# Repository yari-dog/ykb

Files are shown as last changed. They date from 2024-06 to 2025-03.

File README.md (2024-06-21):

## PCB
using 
 - https://github.com/ebastler/marbastlib for choc and controller (0xCB helios) footprints

for whatever reason, the GC9A01 board that i've designed this around uses i2c names instead of spi names, however it does indeed use spi. I've chosen to use the labels printed on the solder mask of the LCD as opposed to the correct SPI ones.

# thanks to pat for double checking my work lmao


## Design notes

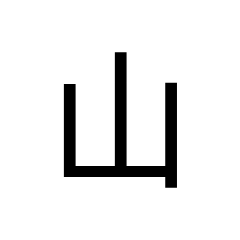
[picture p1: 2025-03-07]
qmk/yama.png

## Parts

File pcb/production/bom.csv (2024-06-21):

Designator | Footprint | Quantity | Value | LCSC Part #
_10, _9, _8, _7, _6, _5, _4, _3, _2, |  | 10
D1, D10, D11, D12, D13, D14, D15, D16, D17, D18, D19, D2, D20, D21, D22, D23, D24, D25, D26, D27, D28, D29, D3, D30, D31, D32, D33, D34, D35, D36, D37, D38, D39, D4, D40, D41, D42, D43, D44, D5, D6, D7, D8, D9 | Diode_SOD-123 | 44 | Diode
J1 | PinHeader_1x07_P2.54mm_Vertical | 1 | Conn_01x07_Socket
S1, S10, S11, S12, S13, S14, S15, S16, S17, S18, S19, S2, S20, S21, S22, S23, S24, S25, S26, S27, S28, S29, S3, S30, S31, S32, S33, S34, S35, S36, S37, S38, S39, S4, S40, S41, S42, S43, S44, S5, S6, S7, S8, S9 | Hotswap_Choc_V1V2_1.00u | 44 | Keyswitch

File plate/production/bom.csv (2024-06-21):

Designator | Footprint | Quantity | Value | LCSC Part #
_5, _4, _3, _2, |  | 5

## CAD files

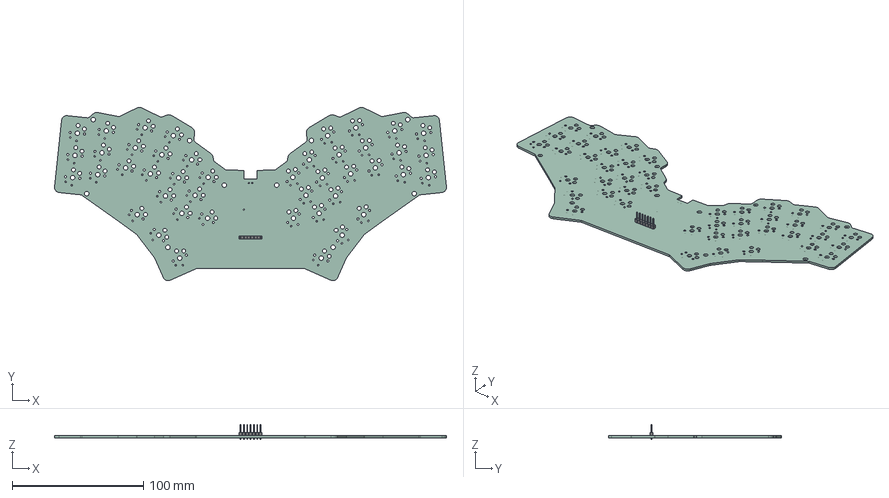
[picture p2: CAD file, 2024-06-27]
pcb/ykb.step
299.2 x 132.3 x 11.5 mm
PinHeader_1x07_P254mm_Vertical
_autosave-ykb_PCB
ykb_PCB

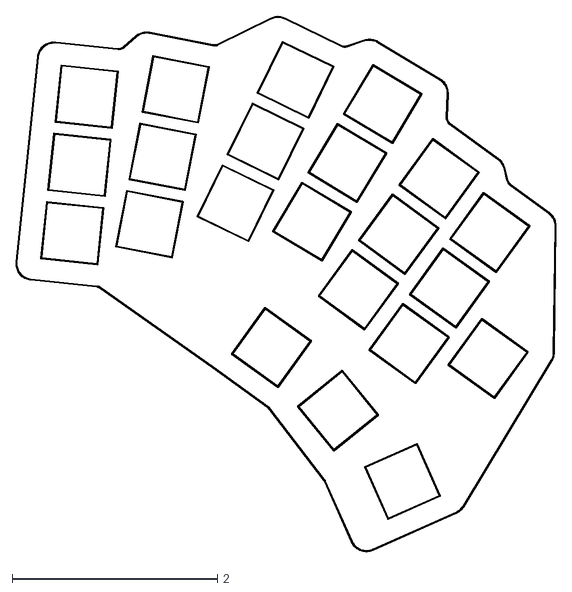
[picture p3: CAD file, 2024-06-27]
plate/yplate-Edge_Cuts.dxf
5.26 x 5.22

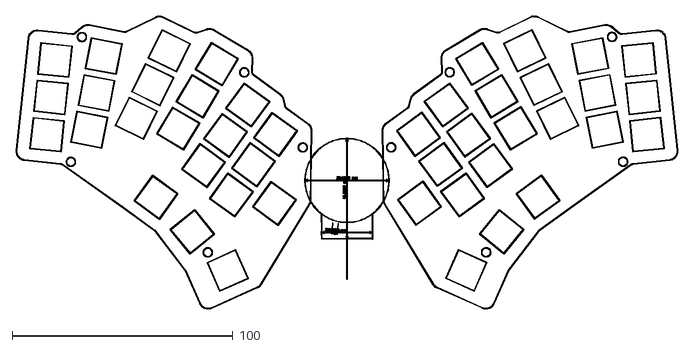
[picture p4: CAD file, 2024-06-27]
pcb/ykb-User_Drawings.dxf
299.4 x 132.5

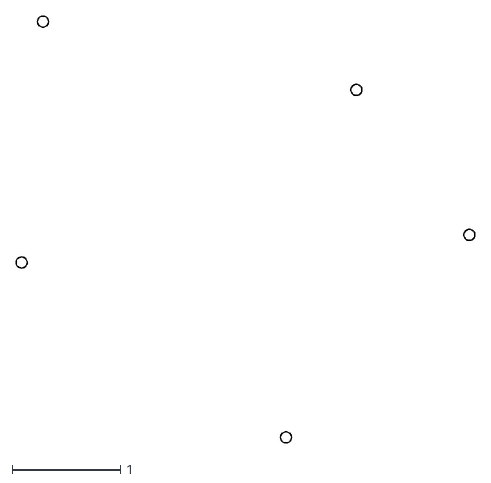
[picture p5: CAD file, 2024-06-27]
plate/yplate-F_Cu.dxf
4.24 x 3.94

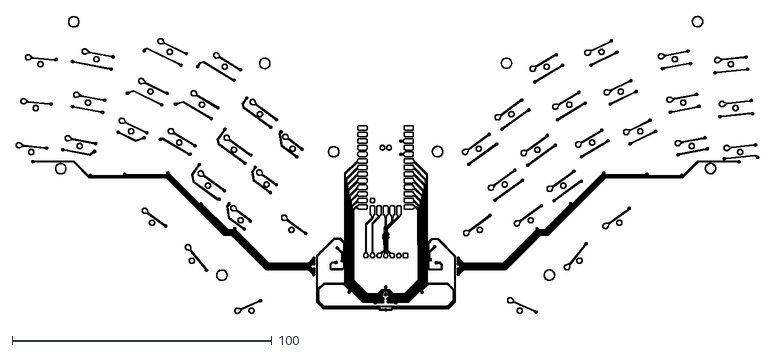
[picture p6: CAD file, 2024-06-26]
pcb/ykb-F_Cu.dxf
285.7 x 114.3

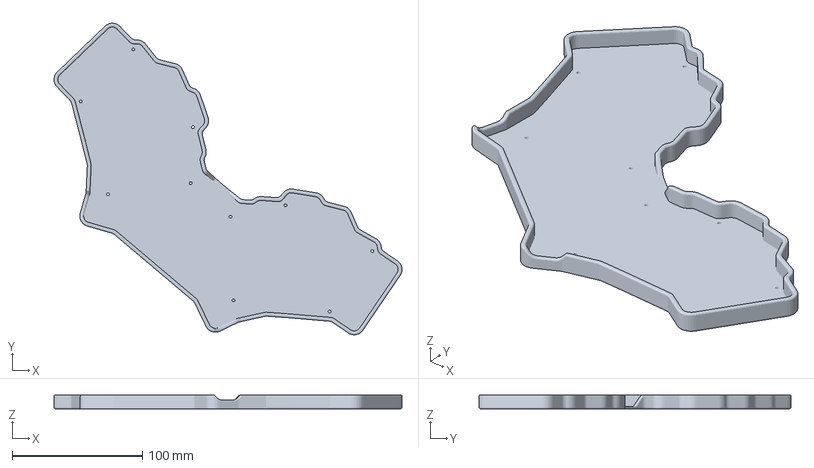
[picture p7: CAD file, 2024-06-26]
pcb/ykb case v47.3mf
267.0 x 239.2 x 11.0 mm

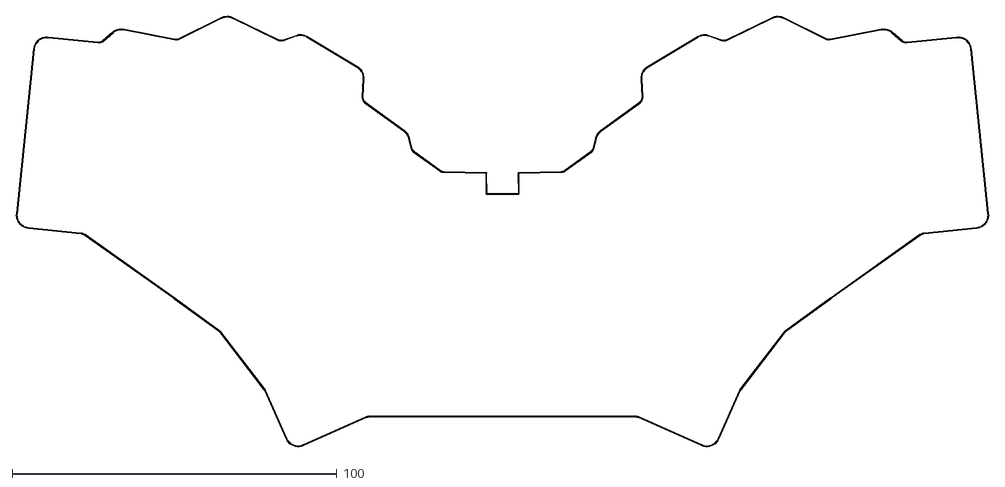
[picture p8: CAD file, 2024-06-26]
pcb/ykb-Edge_Cuts.dxf
299.3 x 132.4

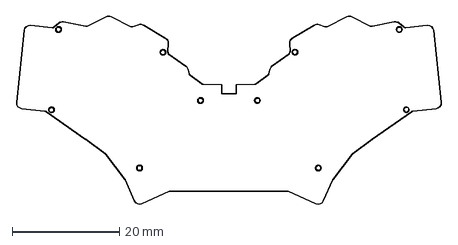
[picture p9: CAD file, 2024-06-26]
pcb/pcb outline with 4mm holes!.dxf
79.2 x 35.2 mm

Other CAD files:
pcb/ImageToStl.com_ykb.obj
pcb/ykb case v47.f3d

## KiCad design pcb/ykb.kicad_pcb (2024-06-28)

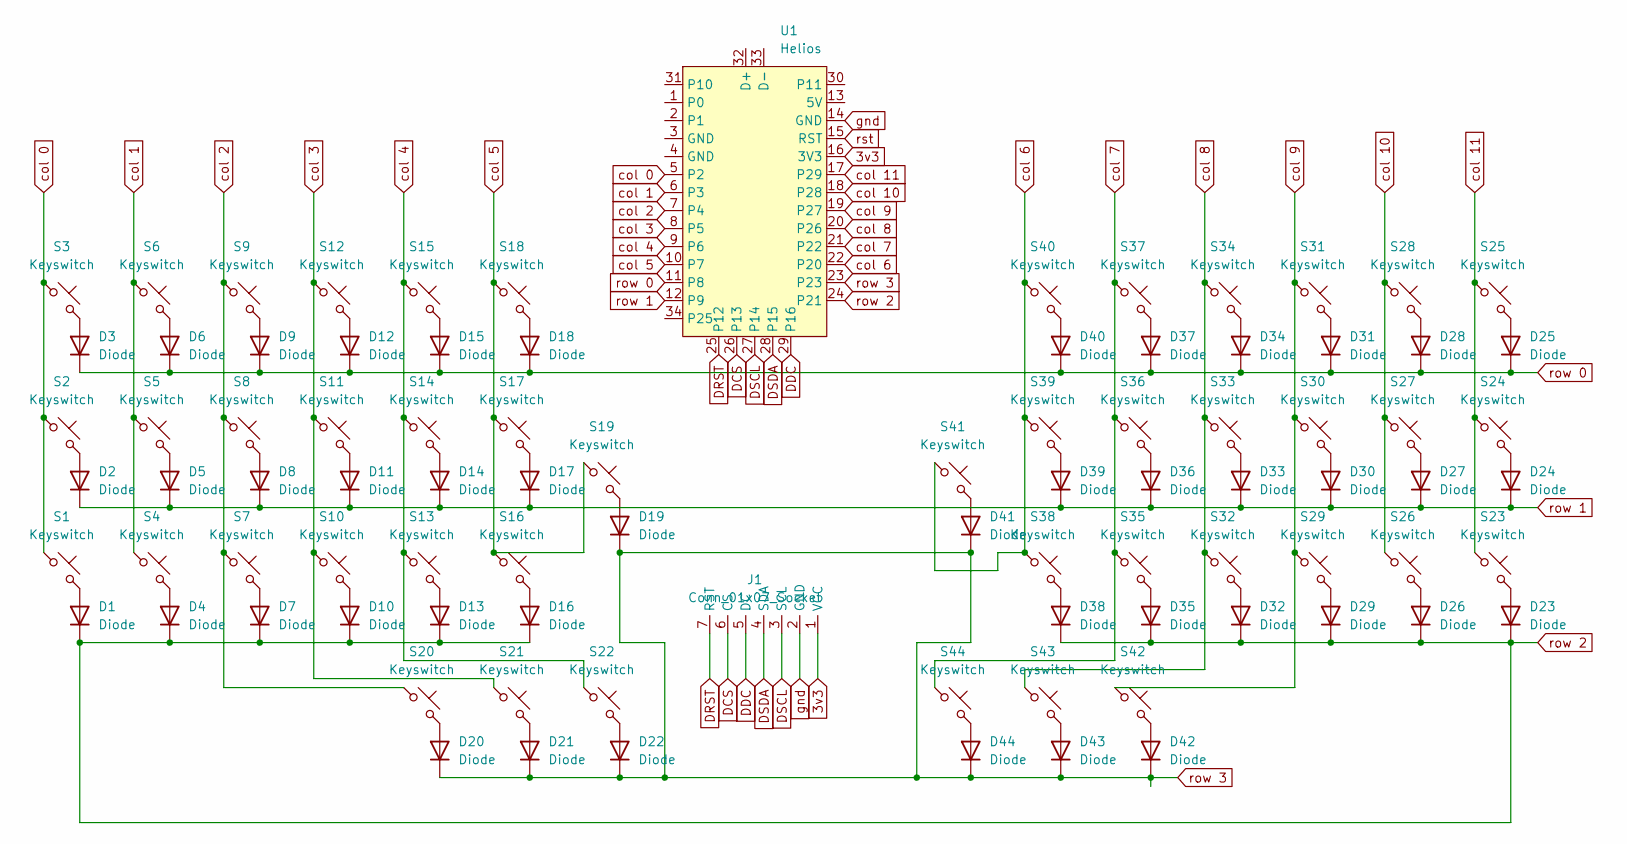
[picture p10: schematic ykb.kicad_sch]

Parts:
D1, D2, D3, D4, D5, D6, D7, D8, D9, D10, D11, D12, D13, D14, D15, D16, D17, D18, D19, D20, D21, D22, D23, D24, D25, D26, D27, D28, D29, D30, D31, D32, D33, D34, D35, D36, D37, D38, D39, D40, D41, D42, D43, D44: Diode; Diode_SOD-123
J1: Conn_01x07_Socket; PinHeader_1x07_P2.54mm_Vertical
S1, S2, S3, S4, S5, S6, S7, S8, S9, S10, S11, S12, S13, S14, S15, S16, S17, S18, S19, S20, S21, S22, S23, S24, S25, S26, S27, S28, S29, S30, S31, S32, S33, S34, S35, S36, S37, S38, S39, S40, S41, S42, S43, S44: Keyswitch; Hotswap_Choc_V1V2_1.00u
U1: Helios; Helios_AC

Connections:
3v3: J1.1 (VCC), U1.16 (3V3)
DCS: J1.6 (CS), U1.26 (P13)
DDC: J1.5 (DC), U1.29 (P16)
DRST: J1.7 (RST), U1.25 (P12)
DSCL: J1.3 (SCL), U1.27 (P14)
DSDA: J1.4 (SDA), U1.28 (P15)
unnamed: D1.2 (A), S1.2
unnamed: D2.2 (A), S2.2
unnamed: D3.2 (A), S3.2
unnamed: D4.2 (A), S4.2
unnamed: D5.2 (A), S5.2
unnamed: D6.2 (A), S6.2
unnamed: D7.2 (A), S7.2
unnamed: D8.2 (A), S8.2
unnamed: D9.2 (A), S9.2
unnamed: D10.2 (A), S10.2
unnamed: D11.2 (A), S11.2
unnamed: D12.2 (A), S12.2
unnamed: D13.2 (A), S13.2
unnamed: D14.2 (A), S14.2
unnamed: D15.2 (A), S15.2
unnamed: D16.2 (A), S16.2
unnamed: D17.2 (A), S17.2
unnamed: D18.2 (A), S18.2
unnamed: D19.2 (A), S19.2
unnamed: D20.2 (A), S20.2
unnamed: D21.2 (A), S21.2
unnamed: D22.2 (A), S22.2
unnamed: D23.2 (A), S23.2
unnamed: D24.2 (A), S24.2
unnamed: D25.2 (A), S25.2
unnamed: D26.2 (A), S26.2
unnamed: D27.2 (A), S27.2
unnamed: D28.2 (A), S28.2
unnamed: D29.2 (A), S29.2
unnamed: D30.2 (A), S30.2
unnamed: D31.2 (A), S31.2
unnamed: D32.2 (A), S32.2
unnamed: D33.2 (A), S33.2
unnamed: D34.2 (A), S34.2
unnamed: D35.2 (A), S35.2
unnamed: D36.2 (A), S36.2
unnamed: D37.2 (A), S37.2
unnamed: D38.2 (A), S38.2
unnamed: D39.2 (A), S39.2
unnamed: D40.2 (A), S40.2
unnamed: D41.2 (A), S41.2
unnamed: D42.2 (A), S42.2
unnamed: D43.2 (A), S43.2
unnamed: D44.2 (A), S44.2
col 0: S1.1, S2.1, S3.1, U1.5 (P2)
col 1: S4.1, S5.1, S6.1, U1.6 (P3)
col 2: S7.1, S8.1, S9.1, S20.1, U1.7 (P4)
col 3: S10.1, S11.1, S12.1, S21.1, U1.8 (P5)
col 4: S13.1, S14.1, S15.1, S22.1, U1.9 (P6)
col 5: S16.1, S17.1, S18.1, S19.1, U1.10 (P7)
col 6: S38.1, S39.1, S40.1, S41.1, U1.22 (P20)
col 7: S35.1, S36.1, S37.1, S44.1, U1.21 (P22)
col 8: S32.1, S33.1, S34.1, S43.1, U1.20 (P26)
col 9: S29.1, S30.1, S31.1, S42.1, U1.19 (P27)
col 10: S26.1, S27.1, S28.1, U1.18 (P28)
col 11: S23.1, S24.1, S25.1, U1.17 (P29)
gnd: J1.2 (GND), U1.14 (GND)
row 0: D3.1 (K), D6.1 (K), D9.1 (K), D12.1 (K), D15.1 (K), D18.1 (K), D25.1 (K), D28.1 (K), D31.1 (K), D34.1 (K), D37.1 (K), D40.1 (K), U1.11 (P8)
row 1: D2.1 (K), D5.1 (K), D8.1 (K), D11.1 (K), D14.1 (K), D17.1 (K), D24.1 (K), D27.1 (K), D30.1 (K), D33.1 (K), D36.1 (K), D39.1 (K), U1.12 (P9)
row 2: D1.1 (K), D4.1 (K), D7.1 (K), D10.1 (K), D13.1 (K), D16.1 (K), D23.1 (K), D26.1 (K), D29.1 (K), D32.1 (K), D35.1 (K), D38.1 (K), U1.24 (P21)
row 3: D19.1 (K), D20.1 (K), D21.1 (K), D22.1 (K), D41.1 (K), D42.1 (K), D43.1 (K), D44.1 (K), U1.23
rst: U1.15 (RST)

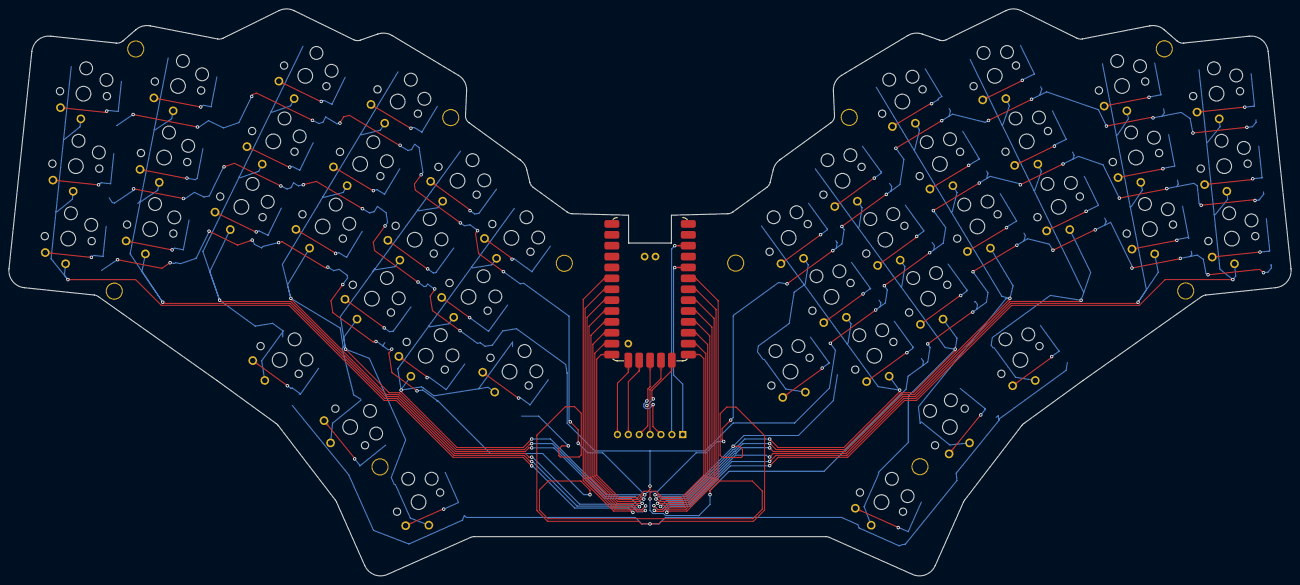
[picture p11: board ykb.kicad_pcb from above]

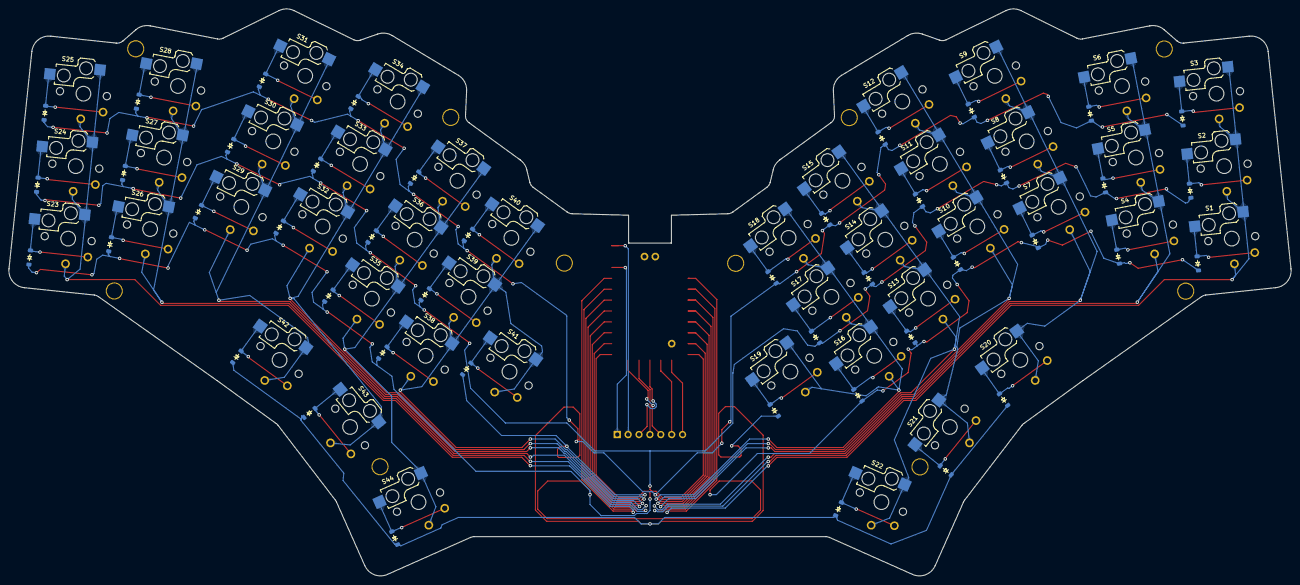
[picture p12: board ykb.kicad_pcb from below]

Board: 2 copper layers, 299.2 x 132.3 mm, 90 parts (44 on the bottom side), 67 nets.

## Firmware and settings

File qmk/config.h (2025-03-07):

#pragma once

#define SPI_DRIVER SPID1
#define DISPLAY_RST GP12
#define DISPLAY_CS GP13
#define SPI_SCK_PIN GP14
#define SPI_MOSI_PIN GP15
#define DISPLAY_DC GP16
#define SPI_MISO_PIN NO_PIN

#define QUANTUM_PAINTER_SUPPORTS_NATIVE_COLORS true

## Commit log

2024-06-15 init, empty pcb files
    [ykb.kicad_pcb, ykb.kicad_sch]
2024-06-15 gitignore and ergogen yaml
    [ykb.kicad_sch]
2024-06-16 proper footprints and s/d connections made
    [ykb.kicad_pcb, ykb.kicad_sch]
2024-06-16 switched to castlated controller :3
    [ykb.kicad_pcb, ykb.kicad_sch]
2024-06-16 switched splay from key units to degrees because i did key units for some reason
    [ykb.kicad_pcb, ykb.kicad_sch]
2024-06-16 fixed cut
    [ykb.kicad_pcb]
2024-06-16 fixed model refs, placed all diodes
    [ykb.kicad_pcb]
2024-06-16 lcd footprint and started routing
    [bom.csv, designators.csv, positions.csv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]
2024-06-16 further routing
    [ykb.kicad_pcb]
2024-06-16 even more routing
    [ykb.kicad_pcb]
2024-06-17 reset row-controller routing, centered things better
    [ykb.kicad_pcb]
2024-06-17 column trace highway
    [ykb.kicad_pcb]
2024-06-17 fixed incorrect net assignment
    [ykb.kicad_pcb]
2024-06-17 finished routing
    [ykb.kicad_pcb]
2024-06-20 all done other than mounting holes :3
    [bom.csv, designators.csv, positions.csv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]
2024-06-21 fixed lcd and some design rule errors
    [ykb.kicad_pcb, ykb.kicad_sch]
2024-06-21 chilled out the routing a little bit lmao
    [ykb.kicad_pcb]
2024-06-21 slight touch-up of display tracks
    [ykb.kicad_pcb]
2024-06-21 diodes on right side
    [ykb.kicad_pcb]
2024-06-21 ideally, finalised routing
    [ykb.kicad_pcb]
2024-06-21 teardrops on pads
    [ykb.kicad_pcb]
2024-06-21 plate started, standoff holes placed
    [ykb.kicad_pcb]
2024-06-21 plate :3
    [bom.csv, designators.csv, positions.csv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]
2024-06-26 case :3
    [ImageToStl.com_ykb.obj, pcb outline with 4mm holes!.dxf, ykb case v47.3mf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]
2024-06-27 some exports so i can print a case lmao
    [ykb-User_Drawings.dxf, ykb.step, yplate-Edge_Cuts.dxf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]
2024-06-28 fixed rebase
    [ykb.kicad_pcb]
2024-06-28 bro git fucked my shit up
    [ykb.kicad_pcb]
